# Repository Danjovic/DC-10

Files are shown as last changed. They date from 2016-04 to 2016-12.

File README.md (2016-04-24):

# DC-10
My implementation of a clock using the C10 decimal time system

In the decimal time system one whole day is divided into 100 intervals which are subsequently divide into 100 'centivals' wich in turn are divided into 100 'ticks'.

Using more familiar base12 time base as a reference we have:

1 tick = 86,4ms

10 ticks = 864ms = 0,864 seconds (a bit less than a second)

100 ticks = 8,64 seconds = 1 centival

1000 ticks = 86,4 seconds = 10 centivals   (1 minute and 26 seconds)

10000 ticks = 864 seconds = 1 interval    (14 minutes and 24 seconds)

10000 ticks = 8640 seconds = 10 intervals (2 hours and 24 minutes)   

100000 ticks = 86400 seconds = 100 intervals (24 hours)

This project implements a very simple digital clock with 4 digits capable of showing centivals and intervals. The least significant digit changes each decival (8,64 seconds) and the most significant turns every 10 intervals (2 hours and 24 minutes)

The circuit is based on a PIC16F628 and four 7-segment displays in a conventional multiplex configuration. One of the displays is turned upside down so we can have two decimal points to separate intervals from decivals.  

The timebase is provided by a 4.0Mhz crystal which generates a tick (86,4ms) using a bresenham algorythm (code borrowed from Roman Black). As a result we have some microseconds of jitter yet imperceptible to the eye.

Each display is turned on by 4ms at a time which gives an overall display refresh rate of 16ms or ~60Hz in terms of frequency. 

There are two buttons to adjust the time. One is for advance the centivals while another advances the intervals. 

The circuit board measures 60x42mm (2.35" x 1.65") and it was designed to be single face friendly with few connections on the upper side and no connection on the top layer is hidden under any component.

The firmware uses the timer0 running at 1:1 thus overflowing exactly each 256us. At every 16 interrupts or 4096us a flag is set to allow the main loop to run. Another flag is set at each tick (86.4ms) and tells the main loop to increment the tick counter. At 100 ticks the main loop calls the function to increment the decivals and after 100 decivals another function is called to increment the intervals. Functions were used to implement the increments to make easy to perform the increments when commanded by the buttons.

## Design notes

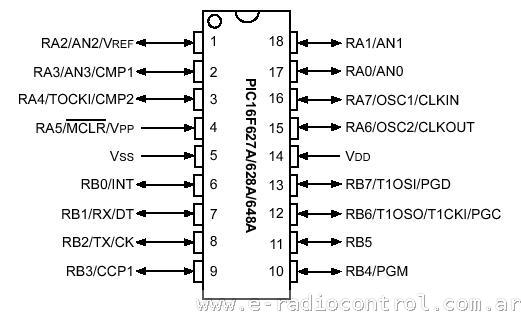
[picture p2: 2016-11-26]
docs/16f628.jpg

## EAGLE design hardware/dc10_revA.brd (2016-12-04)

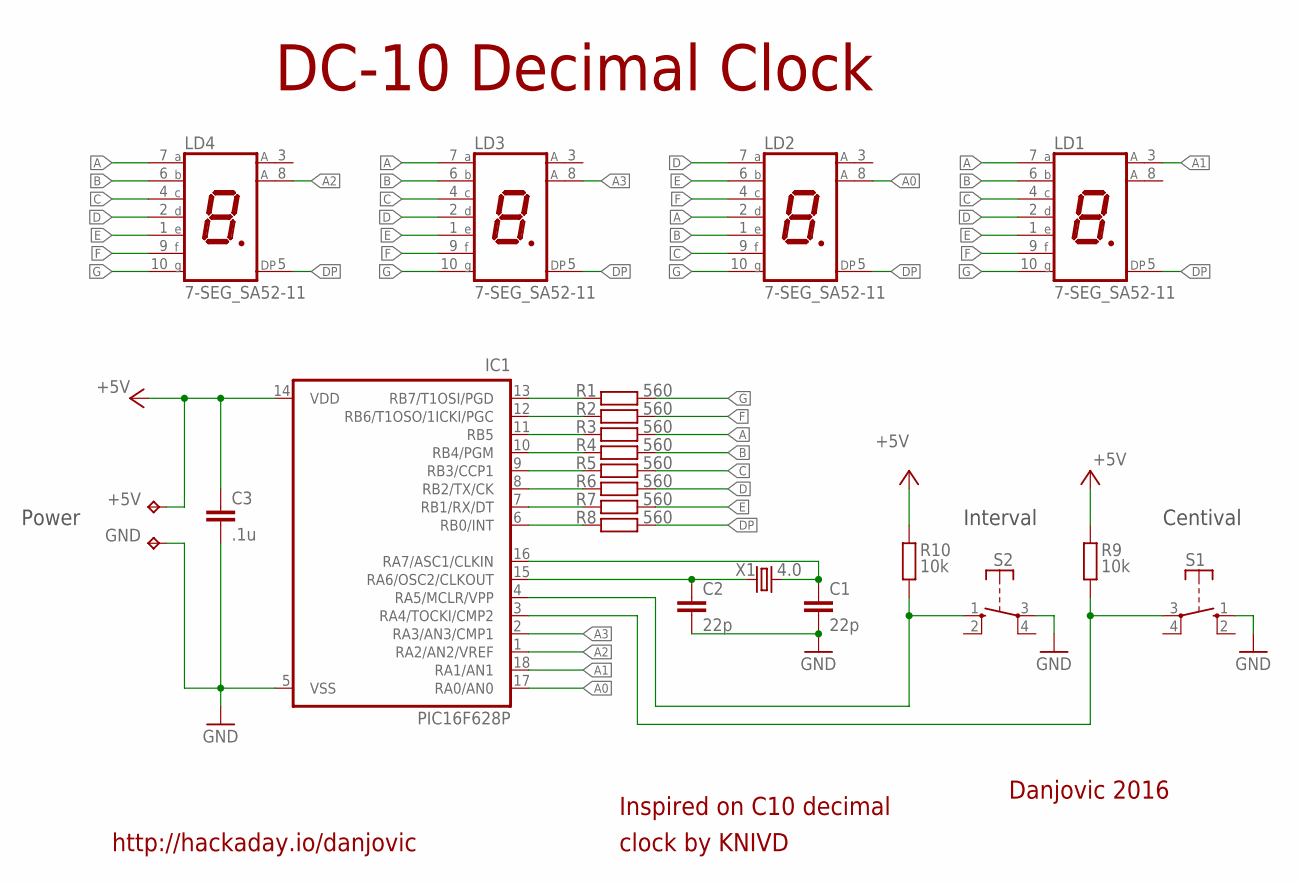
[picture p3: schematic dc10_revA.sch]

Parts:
+5V: TPPAD1-13; P1-13
C1, C2: 22p; C050-024X044
C3: .1u; C050-024X044
GND: TPPAD1-13; P1-13
IC1: PIC16F628P; DIL18
LD1, LD2, LD3, LD4: 7-SEG_SA52-11; SA52-11
R1, R2, R3, R4, R5, R6, R7, R8: 560; 0204/7
R9, R10: 10k; 0204/7
S1, S2: RACON12
X1: 4.0; HC49U-V

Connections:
+5V: +5V.1, C3.1, IC1.14 (VDD), R9.1, R10.1
A: LD1.7 (A), LD2.2 (D), LD3.7 (A), LD4.7 (A), R3.2
A0: IC1.17 (RA0/AN0), LD2.8 (A)
A1: IC1.18 (RA1/AN1), LD1.3 (A)
A2: IC1.1 (RA2/AN2/VREF), LD4.8 (A)
A3: IC1.2 (RA3/AN3/CMP1), LD3.8 (A)
A4: IC1.3 (RA4/TOCKI/CMP2), R9.2, S1.3
A5: IC1.4 (RA5/MCLR/VPP), R10.2, S2.1 (S)
B: LD1.6 (B), LD2.1 (E), LD3.6 (B), LD4.6 (B), R4.2
B0: IC1.6 (RB0/INT), R8.1
B1: IC1.7 (RB1/RX/DT), R7.1
B2: IC1.8 (RB2/TX/CK), R6.1
B3: IC1.9 (RB3/CCP1), R5.1
B4: IC1.10 (RB4/PGM), R4.1
B5: IC1.11 (RB5), R3.1
B6: IC1.12 (RB6/T1OSO/1ICKI/PGC), R2.1
B7: IC1.13 (RB7/T1OSI/PGD), R1.1
C: LD1.4 (C), LD2.9 (F), LD3.4 (C), LD4.4 (C), R5.2
D: LD1.2 (D), LD2.7 (A), LD3.2 (D), LD4.2 (D), R6.2
DP: LD1.5 (DP), LD2.5 (DP), LD3.5 (DP), LD4.5 (DP), R8.2
E: LD1.1 (E), LD2.6 (B), LD3.1 (E), LD4.1 (E), R7.2
F: LD1.9 (F), LD2.4 (C), LD3.9 (F), LD4.9 (F), R2.2
G: LD1.10 (G), LD2.10 (G), LD3.10 (G), LD4.10 (G), R1.2
GND: C1.2, C2.2, C3.2, GND.1, IC1.5 (VSS), S1.1 (S), S2.3
OSC1: C1.1, IC1.16 (RA7/ASC1/CLKIN), X1.2
OSC2: C2.1, IC1.15 (RA6/OSC2/CLKOUT), X1.1

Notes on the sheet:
Interval
Centival
Power
DC-10 Decimal Clock
http://hackaday.io/danjovic
Danjovic 2016
Inspired on C10 decimal
clock by KNIVD

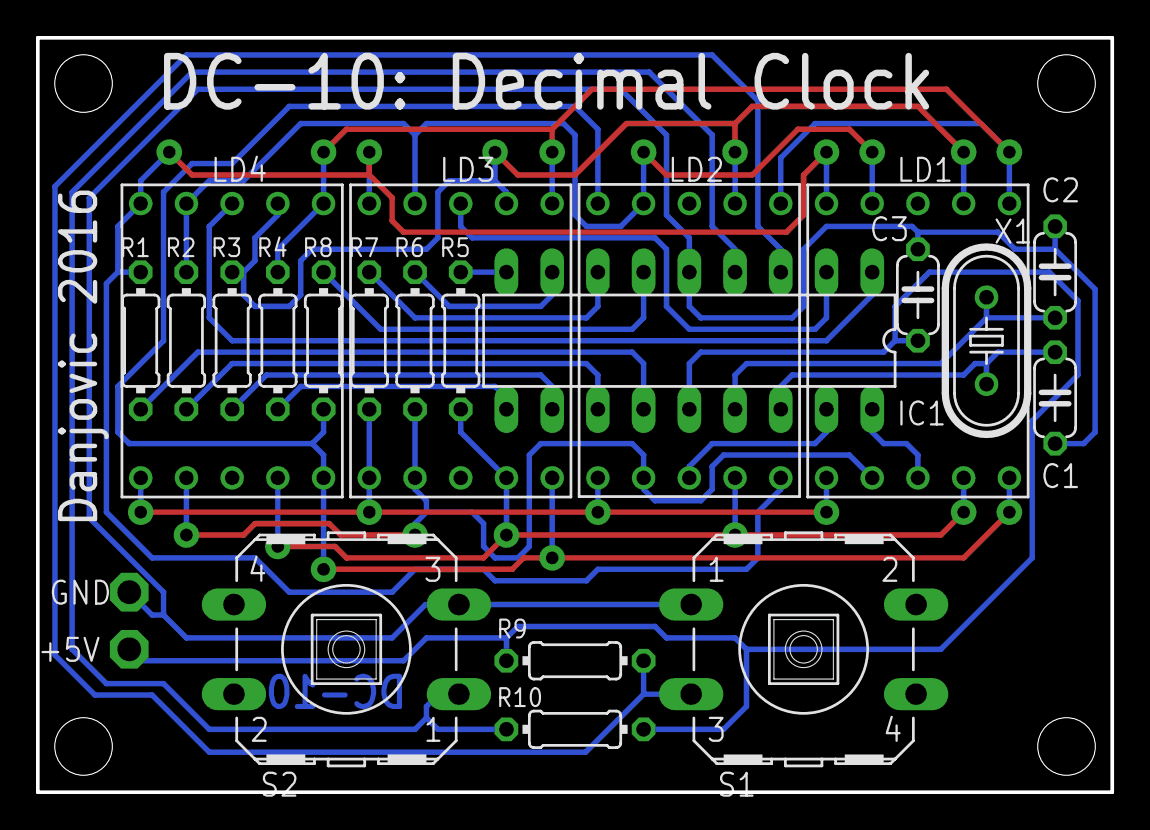
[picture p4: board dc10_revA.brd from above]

Board: 2 copper layers, 59.7 x 41.9 mm, 23 parts (0 on the bottom side), 26 nets.

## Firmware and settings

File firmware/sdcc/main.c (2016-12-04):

/*  
    DC-10 - A C10 clock implementation by Danjovic
	(c) Daniel Jose Viana, 2016 - danjovic@hotmail.com
	Release under GPL V2.0

	V0.1  - April 23, 2016 - basic implementation
	V0.2  - November 26, 2016 - Ported to SDCC
	V0.21 - November 28, 2016 - Changed to common cathode displays
*/

#include <pic16f628a.h>
#include <stdint.h>
#include <stdbool.h>

uint16_t __at _CONFIG configWord = _HS_OSC & _WDT_OFF & _PWRTE_ON & _MCLRE_OFF & _BODEN_OFF & _LVP_OFF &  _CPD_OFF &  _CP_OFF; 


// ****** Definitions ******

#define _t40ms 10

// Common Cathode displays
//           GFABCDE.
#define _0 0b01111110
#define _1 0b00011000
#define _2 0b10110110
#define _3 0b10111100
#define _4 0b11011000
#define _5 0b11101100
#define _6 0b11101110
#define _7 0b00111000
#define _8 0b11111110
#define _9 0b11111100

/*
// Common Anode displays
//           GFABCDE.
#define _0 ~0b01111110
#define _1 ~0b00011000
#define _2 ~0b10110110
#define _3 ~0b10111100
#define _4 ~0b11011000
#define _5 ~0b11101100
#define _6 ~0b11101110
#define _7 ~0b00111000
#define _8 ~0b11111110
#define _9 ~0b11111100
*/

/*
// Prototype pinout
//            D.CGBFAE
#define _0 ~0b10101111
#define _1 ~0b00101000
#define _2 ~0b10011011
#define _3 ~0b10111010
#define _4 ~0b00111100
#define _5 ~0b10110110
#define _6 ~0b10110111
#define _7 ~0b00101010
#define _8 ~0b10111111
#define _9 ~0b10111110
*/

#define _decimal_point (1<<0) // bit where dp is mapped

#define BUTTON1 ((PORTA & (1<<4)))  // RA4
#define BUTTON2 ((PORTA & (1<<5)))  // RA5
#define BYTE unsigned char


// ****** Constants ******
// const unsigned char common[4] = { 1, 2, 4, 8 }; // pins activated for common anode (prototype only)

// const unsigned char common[4] = { 4, 8, 1, 2 }; // pins activated for common anode 
const unsigned char common[4] = { ~4, ~8, ~1, ~2 }; // pins activated for common cathode
const unsigned char digits[10] = { _0,_1,_2,_3,_4,_5,_6,_7,_8,_9 };
  

// ****** Variables ******
static volatile unsigned char go=0;
static volatile unsigned char go_counter=0;
static volatile unsigned char new_tick=0; // 4ms tick
  
unsigned char tick_01=0;
unsigned char tick_10=0;
unsigned char interval_01=0;
unsigned char interval_10=0;
unsigned char centival_01=0;
unsigned char centival_10=0;

unsigned char digit=0;
unsigned char display [4] = { _0,_0,_0,_0 };
unsigned char Time_B1_Pressed,Time_B2_Pressed=0;

static uint32_t bres=0; 


// ****** Interrupts ******
	
//static void isr(void) interrupt 0 {	
static void irqHandler(void) __interrupt 0 {
	// interrupt each 256us
	bres+=256;
	if (bres>=86400) { 
		bres=bres-86400;
		new_tick=1;
	}
	if ((++go_counter&15) == 0) go=1;
	
	T0IF = 0;
}


// ****** Functions ******
unsigned char advance_tick(void) {
	unsigned char r=0;
	// increment units and tenths
	if ((++tick_01)>9) {
		tick_01=0;
		
		if ((++tick_10)>9){
			tick_10=0;
			r=1;   // overflow
		}
		// update display each 10 ticks (0,864s)
		display [1] ^= _decimal_point;
		display [2] ^= _decimal_point;	
	}
	return r;
}


unsigned char advance_centival(void) {
	unsigned char r=0;
	// increment units and tenths
	if ((++centival_01)>9) {
		centival_01=0;
		if ((++centival_10)>9){
			centival_10=0;
			r=1;   // overflow
		}
	}
	// update display
	display [3] = digits[centival_01];
	display [2] = digits[centival_10];	
	return r;
}


unsigned char advance_interval(void) {
	unsigned char r=0;
	// increment units and tenths
	if (++interval_01>9) {
		interval_01=0;
		if (++interval_10>9){
			interval_10=0;
			r=1;   // overflow
		}
	}
	// update display
	display [1] = digits[interval_01];
	display [0] = digits[interval_10];		
	return r;
}

void init_hw(void){
	// initialize I/O ports
	TRISB=0b00000000; // All as outputs (segments) 
	TRISA=0b11110000; // bits [3..0] as outputs (common a/k)

	// initialize prescale and interrupts
	OPTION_REG = 0b11011111;  // Timer0 internal clock, 1:1 rate (prescaler to wdt)
	TMR0  =0;
	T0IF  = 0;
	INTCON     = 0b10100000;  // enable timer0 and global interrupts
}


// ****** Main ******
void main (void) {
	init_hw(); // Initialize hardware
		
	// main loop
	for (;;){
		while (!go); // wait for 4ms flag
		go=0;        // reset go flag
		
		// check if new tick (84,4ms or ~21/22 go's) 
		if (new_tick) {
			new_tick=0;
			if (advance_tick()) {
				if (advance_centival()) {
					advance_interval();
				}
			}
		}
		
		// update display
		++digit;
		digit&=3;  // next digit to display
		PORTA=common[digit];
		PORTB=display[digit]; // update display

		// Test for buttons
		if (BUTTON1) { // button pressed
			if (Time_B1_Pressed<255) Time_B1_Pressed++;	
		} else {       // Release
			if (Time_B1_Pressed > _t40ms) {
				advance_centival();
			}
			Time_B1_Pressed =0;
		}

		if (BUTTON2) { // button pressed
			if (Time_B2_Pressed<255) Time_B2_Pressed++;	
		} else {       // Release
			if (Time_B2_Pressed > _t40ms) {
				advance_interval();
			}
			Time_B2_Pressed =0;
		}		
	} // end of main loop
}

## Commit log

2016-04-24 Basic Release
    [dc10.brd, dc10.sch]
2016-11-26 First run on prototype
    [dc10.brd, dc10.sch, dc10_revA.brd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]
2016-11-26 Button behavior corrected
2016-12-04 Revised PCB / Clock set tool
    Increased spacing between tracks to ease the production of homemade
    boards.
    Added a python script to generate dual clock with conventional and
    decimal time.
    [dc10_revA.brd]
2016-12-04 corrected unintentional code merge
    [main.c]
